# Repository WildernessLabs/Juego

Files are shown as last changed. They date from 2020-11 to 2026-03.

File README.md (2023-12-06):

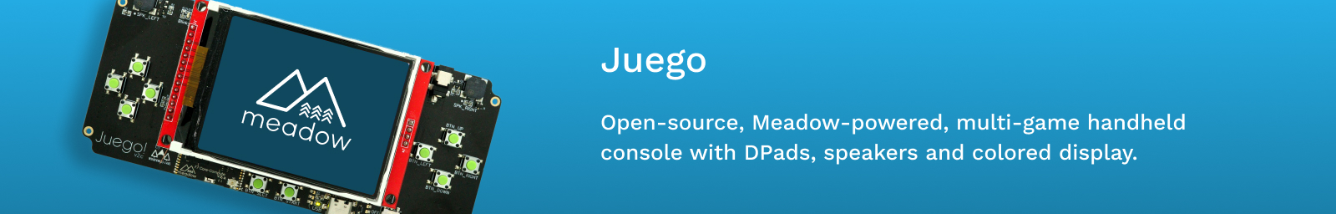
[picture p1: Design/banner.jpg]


# Juego

Open-source, Meadow-powered, multigame handheld console with DPads, speakers and a colored display.

#### Are you brand new to Meadow?

If you've never deployed a Meadow app before, you'll want to check out the [Getting Started Guide](https://developer.wildernesslabs.co/Meadow/Getting_Started/) which will get your development environment up and running and validate that you can build and deploy.

## Contents
* [Purchasing or Building](#purchasing-or-building)
* [Getting Started](#getting-started)
* [Hardware Specifications](#hardware-specifications)
* [Additional Samples](#additional-samples)
* [Juego Hack Kit Version](#juego-hack-kit-version)
* [Support](#support)

## Purchasing or Building

<table width="100%">
    <tr>
        <td>
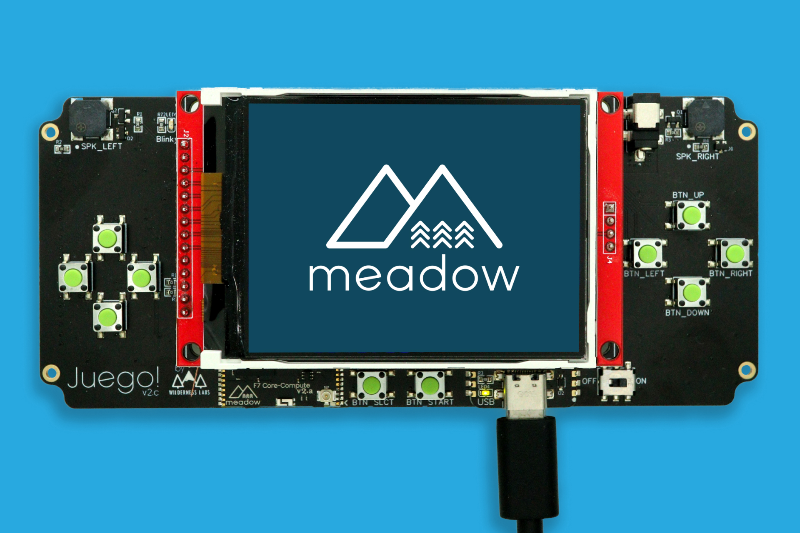
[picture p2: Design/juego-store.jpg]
            
        </td>
        <td>
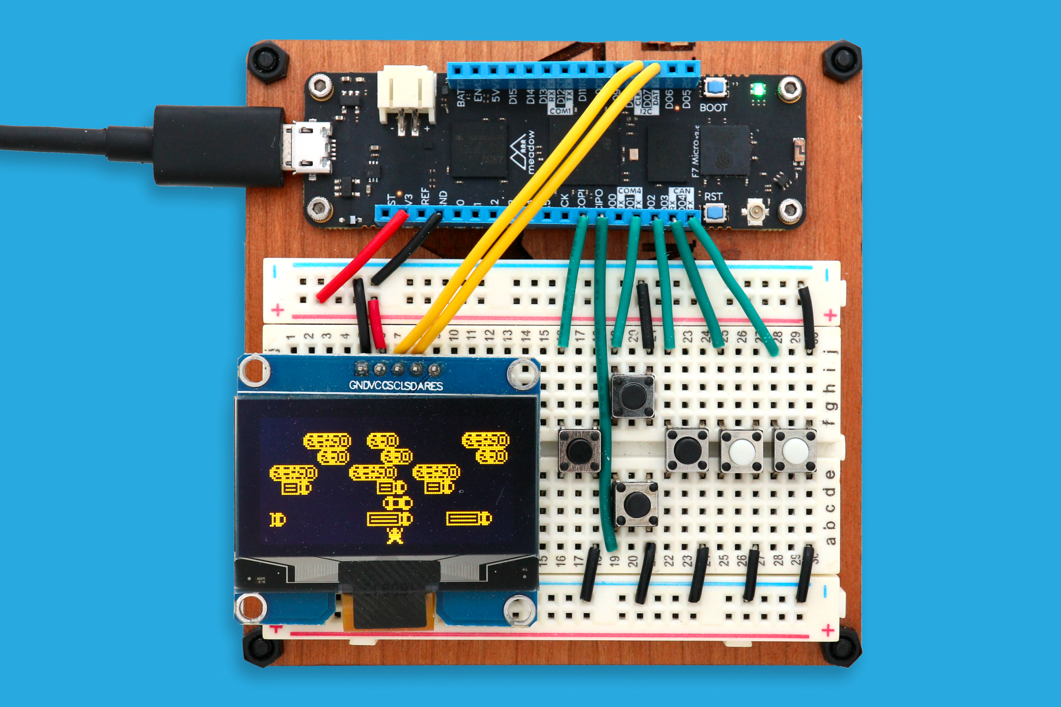
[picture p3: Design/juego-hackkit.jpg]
             
        </td>
    </tr>
    <tr>
        <td>
            You can get a Juego board from the <strong><a href="https://store.wildernesslabs.co/collections/frontpage/products/juego">Wilderness Labs store</a></strong>.
        </td>
        <td> 
            You can also build a simpler Juego using a monocolor display and push buttons.
        </td>
    </tr>
</table>

## Getting Started

### Playing Juego

Do you have a brand new Juego and you just wanna play some games? Check out the [Juego.Samples repo](https://github.com/WildernessLabs/Juego.Samples) with some games you can play out of the box:

Screenshot of the Juego.Samples repo readme showing several games that can be played. (https://github.com/WildernessLabs/Juego.Samples)

#### Are you brand new to Meadow?

If you've never deployed a Meadow app before, you'll want to check out the [Getting Started Guide](https://developer.wildernesslabs.co/Meadow/Getting_Started/) which will get your development environment up and running and validate that you can build and deploy.

### Using the Juego Hardware in your own App

To make using the hardware even simpler, we've created a [NuGet package](https://www.nuget.org/packages/Meadow.Juego) that instantiates and encapsulates the onboard hardware into a `Juego` class.

1. Add the ProjectLab Nuget package your project: 
    - `dotnet add package Meadow.Juego`, or
    - [Meadow.Juego Nuget Package](https://www.nuget.org/packages/Meadow.Juego)
    - [Explore in Fuget.org](https://www.fuget.org/packages/Meadow.Juego/0.1.0/lib/netstandard2.1/Juego.dll/Meadow.Devices/Juego)

2. Instantiate the Juego class:
```csharp
public class MeadowApp : App<F7CoreComputeV2>
{
    IJuegoHardware juego;

    public override Task Initialize()
    {
        juego = Juego.Create();
        ...
```

3. Access `Juego`'s onboard peripherals.

- To create a MicroGraphics object with Juego's Display:
```csharp
    ...
    if (juego.Display is { } display)
    {
        graphics = new MicroGraphics(display)
        {
            IgnoreOutOfBoundsPixels = true,
            CurrentFont = new Font12x16()
        };
        ....
    }
    ...
```

- To instantiate Juego's Select and Start buttons:
```csharp
    ...
    if (juego.SelectButton is { } selectButton)
    {
        selectButton.PressStarted += (s, e) => { ... };
        selectButton.PressEnded += (s, e) => { ... };
    }

    if (juego.StartButton is { } startButton)
    {
        startButton.PressStarted += (s, e) => { ... };
        startButton.PressEnded += (s, e) => { ... };
    }
    ...
```
- To use Juego's speakers:
```csharp
    ...
    for (int i = 0; i < 5; i++)
    {
        await juego.LeftSpeaker.PlayTone(
            new Frequency(440), TimeSpan.FromMilliseconds(500));
        await juego.RightSpeaker.PlayTone(
            new Frequency(540), TimeSpan.FromMilliseconds(500));
    }
    ...
```

## Hardware Specifications

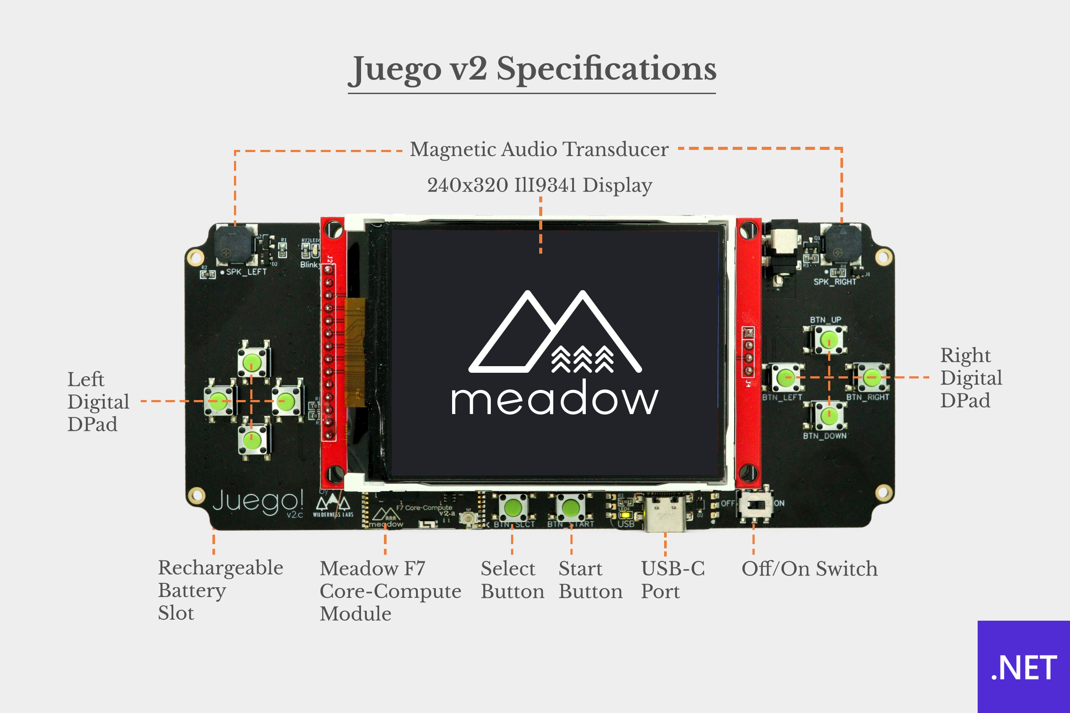
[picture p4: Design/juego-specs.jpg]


<table>
    <tr>
        <td><strong>ILI9341</strong> - 240x320 RGB LED display</td>
    </tr>
    <tr>
        <td><strong>Magnetic Audio Transducers</strong> - A pair of High quality piezo speakers</td>
    </tr>
    <tr>
        <td><strong>DPads</strong> - Directional Pads on either side of the display.</td>
    </tr>
    <tr>
        <td><strong>Select/Start Buttons</strong> - Classical Select and Start buttons</td>
    </tr>
    <tr>
        <td><strong>USB-C port</strong> - Port used to build/deploy apps to Juego</td>
    </tr>
    <tr>
        <td><strong>Rechargable Battery Slot</strong> - To play on the go</td>
    </tr>
    <tr>
        <td><strong>On/Off switch</strong> - Used to turn the Juego on and off</td>
    </tr>
</table>

You can find the schematics and other design files in the [Hardware folder](Source/Hardware).

## Additional Samples

1. **[Setup your Meadow Build Environment](http://developer.wildernesslabs.co/Meadow/Getting_Started/Deploying_Meadow/)** - If you haven't deployed a Meadow app before, you'll need to setup your IDE extension(s), deploy Meadow.OS, etc.
2. **[Run the Demo App](Source/Juego_Demo/)** - Deploy the Juego demonstration app to see the built in peripherals at work.
3. **[Check out the Juego.Samples repo](https://github.com/WildernessLabs/Juego.Samples)** - We recommend cloning the [Juego.Samples](https://github.com/WildernessLabs/Juego.Samples) repo. There you'll find a bunch of awesome samples that you can run right out-of-the box! 
<a href="https://github.com/WildernessLabs/Juego.Samples">
    juego, iot, project, samples
</a>

## Juego Hack Kit Version

This was an early hardware project to create a Meadow handheld multi-game project designed to work with 128x64 or 320x240 single color displays (SSD1306 or SSD1309)

Includes five games:

- FrogIt
- Pong
- Span4 (2-player match 4 game)
- Snake
- Tetraminos (inspired by Tetris)

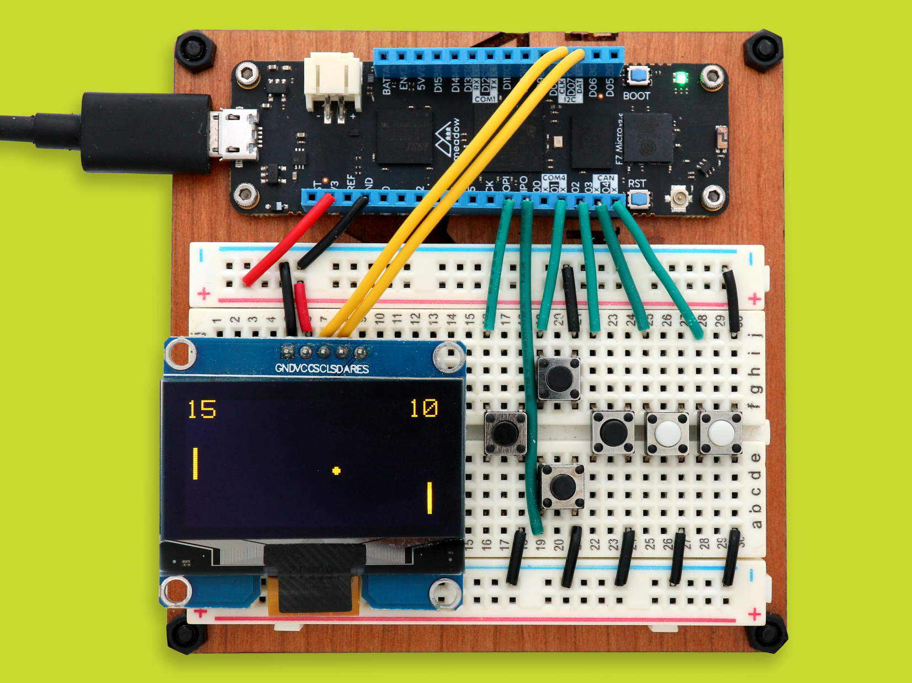
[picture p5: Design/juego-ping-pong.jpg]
"Image of Juego Meadow prototype hardware"


### Fritzing Diagrams of Juego using a Meadow Dev Kit

<table width="100%">
    <tr>
        <td>
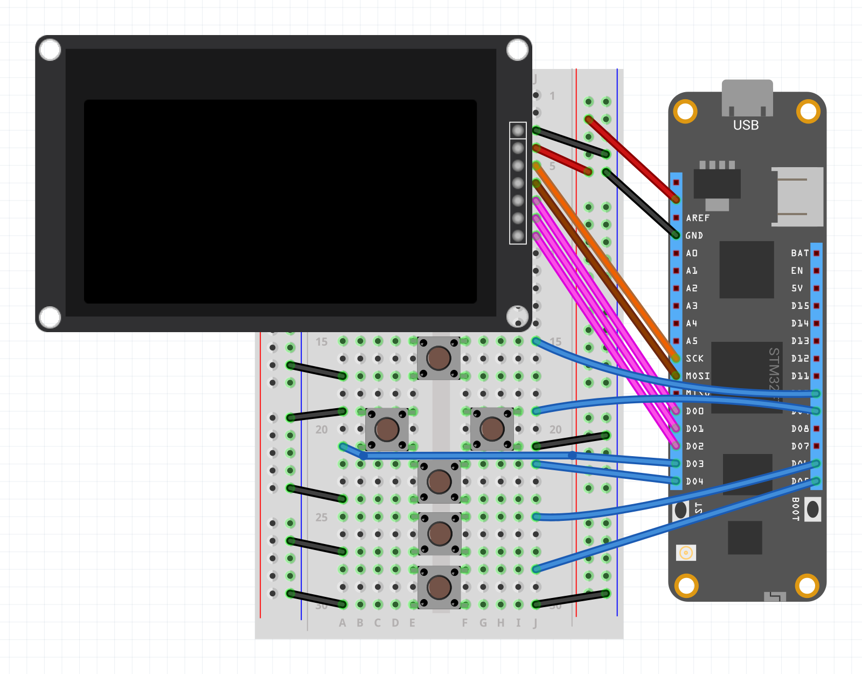
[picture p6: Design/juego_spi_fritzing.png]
            
        </td>
        <td>
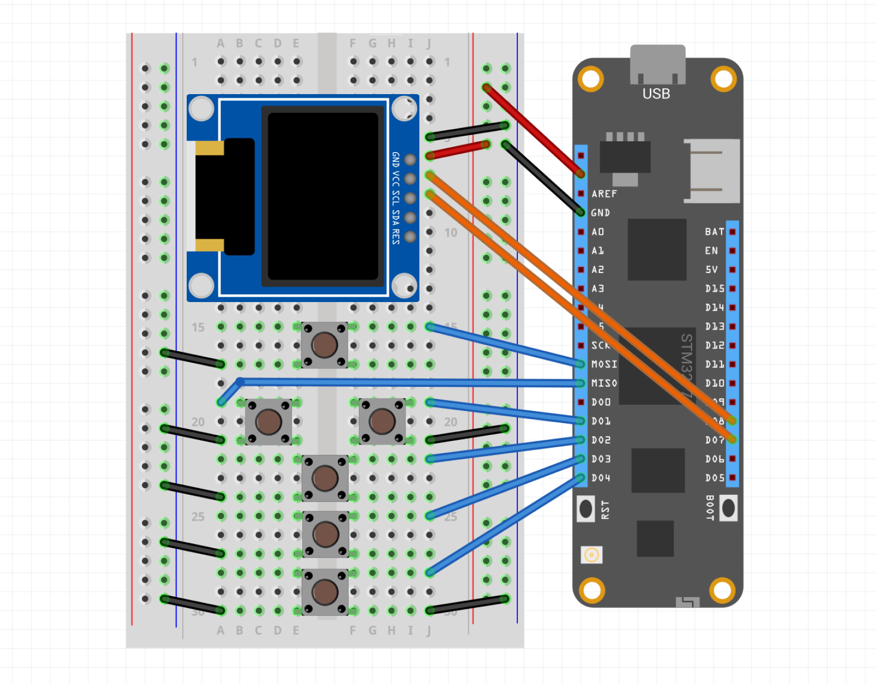
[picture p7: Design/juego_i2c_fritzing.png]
             
        </td>
    </tr>
    <tr>
        <td>
            Juego using a SSD1309 Display connected via SPI and Push Buttons.
        </td>
        <td> 
            Juego using a SSD1309 Display connected via I2C and Push Buttons.
        </td>
    </tr>
</table>

## Support

Having trouble building/running these projects? 
* File an [issue](https://github.com/WildernessLabs/Meadow.Desktop.Samples/issues) with a repro case to investigate, and/or
* Join our [public Slack](http://slackinvite.wildernesslabs.co/), where we have an awesome community helping, sharing and building amazing things using Meadow.

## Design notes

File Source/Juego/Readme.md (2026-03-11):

# Meadow.Juego

**Convenience library for the Meadow Juego handheld game console**

The **Juego** library is included in the **Meadow.Juego** nuget package and is designed for the [Wilderness Labs](www.wildernesslabs.co) Meadow .NET IoT platform.

Juego is an open-source, Meadow-powered, multigame handheld console with dual DPads, stereo speakers, and a color display.

For more information on developing for Meadow, visit [developer.wildernesslabs.co](http://developer.wildernesslabs.co/).

To view all Wilderness Labs open-source projects, including samples, visit [github.com/wildernesslabs](https://github.com/wildernesslabs/).

## Onboard Hardware

| Peripheral | Description |
|---|---|
| ILI9341 | 240x320 color TFT display |
| BMI270 | Inertial measurement unit / accelerometer |
| Left DPad | 4-way directional pad (left side) |
| Right DPad | 4-way directional pad (right side) |
| Select / Start | Classic game console buttons |
| Piezo speakers | Stereo left and right audio transducers |
| USB-C | Build and deploy port |
| Battery slot | Rechargeable battery for portable play |

## Installation

You can install the library from within Visual Studio using the NuGet Package Manager or from the command line using the .NET CLI:

`dotnet add package Meadow.Juego`

## Usage

```csharp
public class MeadowApp : App<F7CoreComputeV2>
{
    IJuegoHardware juego;

    public override Task Initialize()
    {
        juego = Juego.Create();

        if (juego.Display is { } display)
        {
            var graphics = new MicroGraphics(display)
            {
                IgnoreOutOfBoundsPixels = true,
                CurrentFont = new Font12x16()
            };
            graphics.DrawText(10, 10, "Hello, Juego!");
            graphics.Show();
        }

        if (juego.Left_UpButton is { } upButton)
        {
            upButton.PressStarted += (s, e) => Resolver.Log.Info("Up pressed");
        }

        if (juego.SelectButton is { } selectButton)
        {
            selectButton.PressStarted += (s, e) => Resolver.Log.Info("Select pressed");
        }

        if (juego.MotionSensor is { } imu)
        {
            imu.Updated += (s, e) =>
                Resolver.Log.Info($"X:{e.New.Acceleration3D?.X.Gravity:0.0}g");
        }

        return Task.CompletedTask;
    }

    public override async Task Run()
    {
        if (juego.MotionSensor is { } imu)
            imu.StartUpdating(TimeSpan.FromMilliseconds(250));

        if (juego.LeftSpeaker != null)
            await juego.LeftSpeaker.PlayTone(new Frequency(440), TimeSpan.FromMilliseconds(500));

        if (juego.RightSpeaker != null)
            await juego.RightSpeaker.PlayTone(new Frequency(540), TimeSpan.FromMilliseconds(500));

        await Task.Delay(Timeout.Infinite);
    }
}
```

## How to Contribute

- **Found a bug?** [Report an issue](https://github.com/WildernessLabs/Meadow_Issues/issues)
- Have a **feature idea or driver request?** [Open a new feature request](https://github.com/WildernessLabs/Meadow_Issues/issues)
- Want to **contribute code?** Fork the [Juego](https://github.com/WildernessLabs/Juego) repository and submit a pull request against the `develop` branch

## Need Help?

If you have questions or need assistance, please join the Wilderness Labs [community on Slack](http://slackinvite.wildernesslabs.co/).

## About Meadow

Meadow is a complete, IoT platform with defense-grade security that runs full .NET applications on embeddable microcontrollers and Linux single-board computers including Raspberry Pi and NVIDIA Jetson.

### Build

Use the full .NET platform and tooling such as Visual Studio and plug-and-play hardware drivers to painlessly build IoT solutions.

### Connect

Utilize native support for WiFi, Ethernet, and Cellular connectivity to send sensor data to the Cloud and remotely control your peripherals.

### Deploy

Instantly deploy and manage your fleet in the cloud for OtA, health-monitoring, logs, command + control, and enterprise backend integrations.

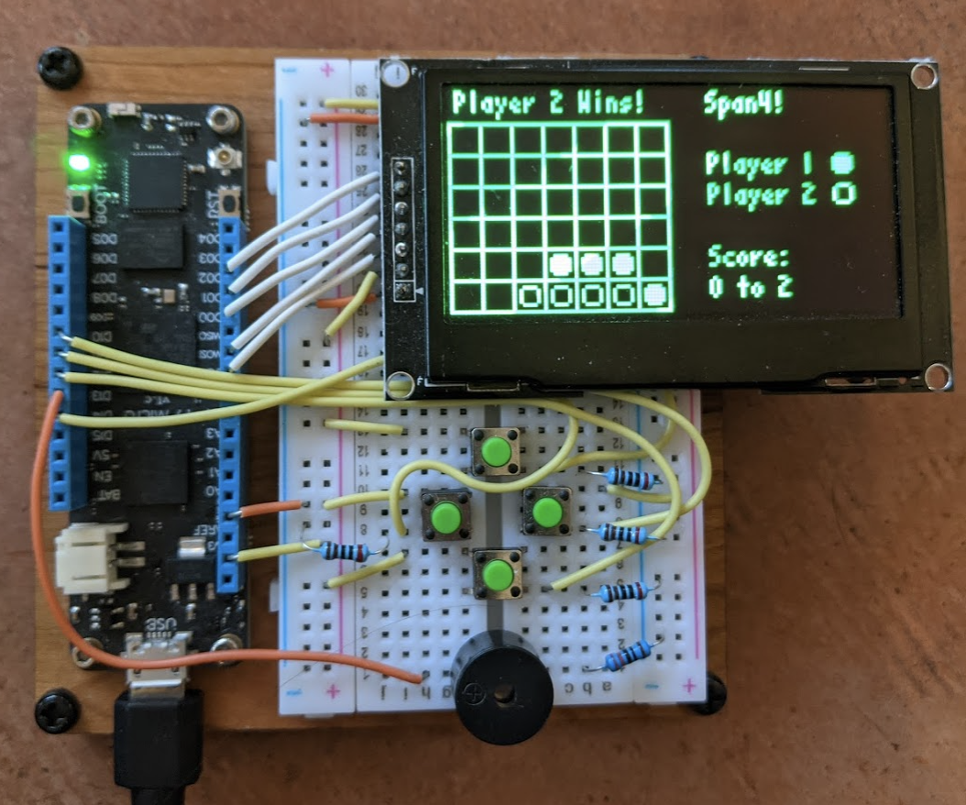
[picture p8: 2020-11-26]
Design/juego.png

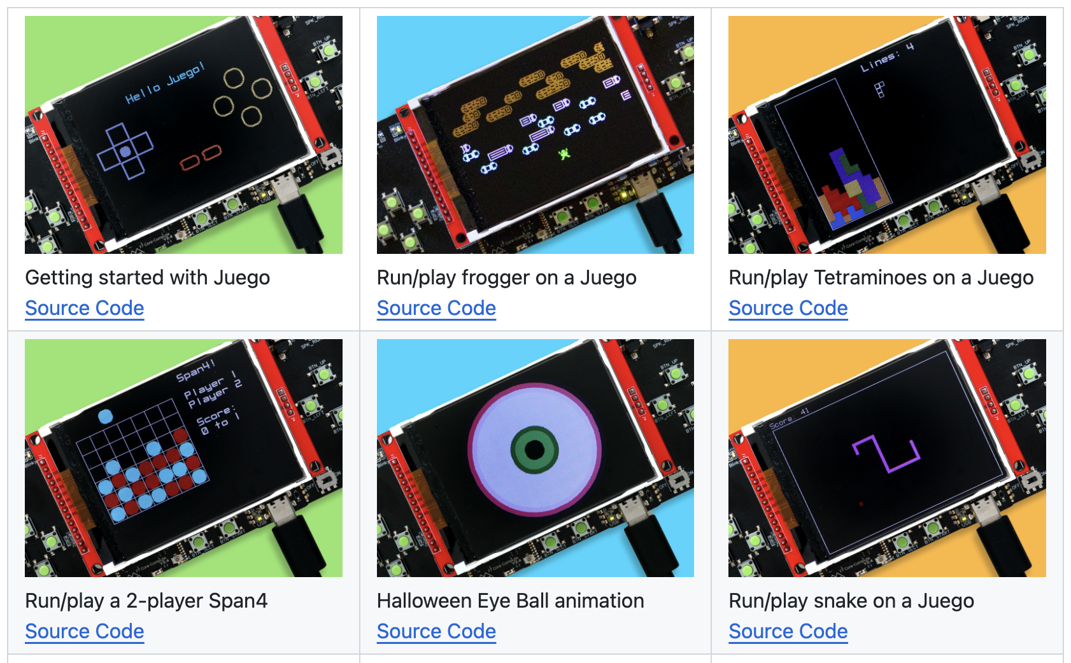
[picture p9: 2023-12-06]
Juego.Samples_Screenshot.png

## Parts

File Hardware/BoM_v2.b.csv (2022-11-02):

ID | Name | Designator | Footprint | Quantity | Manufacturer Part | Manufacturer | Supplier | Supplier Part | Price
1 | Up | BTN_DOWN,BTN_LEFT,BTN_RIGHT,BTN_SLCT,BTN_START,BTN_UP,DPAD_DOWN,DPAD_LEFT,DPAD_RIGHT,DPAD_UP | TACTILE_SWITCH_TALL | 10
2 | BAS70KFILM | D1,D2 | SOT323 | 2 | BAS70KFILM | ST Microelectronics
3 | PJ-030CH-SMT-TR | J1 | CUI_PJ-030CH-SMT-TR | 1
4 | EAST1608GA0 | LED5 | LED0603-RD | 1 | EAST1608GA0 | Everlight
5 | FDV305N | Q1,Q2 | SOT-23_L2.9-W1.3-P0.95-LS2.4-BR | 2 | FDV305N | Fairchild |  | C65189 | 0.044
6 | 10kΩ | R1,R3 | R0603 | 2 | RC0603FR-0710KL | Yageo
7 | 20Ω | R2,R4 | R0603 | 2 | RC0603FR-0720RL | Yageo
8 | 4.7k | R5,R6 | R0603 | 2 | RC0603FR-074K7L | Yageo
9 | 2k | R72 | R0603 | 1 | RC0603FR-072KL | Yageo
10 | 452403012014 | S1 | 452403012014 | 1
11 | CMT-7525-80-SMT | SPK_LEFT,SPK_RIGHT | CMT-7525S | 2 | CMT-7525-80-SMT | CUI Devices
12 | Meadow Core-Compute USB-C, Power, Boot, and Reset Addon Module | U1 | MEADOW CORE-COMPUTE USB-C, POWER, BOOT, RESET ADDON MODULE | 1 |  | Wilderness Labs
13 | 1043P | U3 | BAT-TH_KEYSTONE-1043P | 1 | 1043P | Keystone | Digi-Key
14 | JOYSTICK-PSP1000 | U4 | JOYSTICK-PSP1000 | 1
15 | Meadow Core-Compute Addon Module - Solar Battery Power | U6 | MEADOW CORE-COMPUTE SOLAR & BATTERY POWER ADDON MODULE | 1 |  | Wilderness Labs
16 | Meadow F7v2 Core-Compute Module - Logical | U7 | MEADOW_F7V2_CORE_COMPUTE | 1 |  | Wilderness Labs
17 | ILI9341 LCD TFT 3.2 | U8 | ILI9341 TFT LCD 3.2" | 1
18 | MCP23008T-E/SS | U9,U11,U12 | SSOP-20_L7.2-W5.3-P0.65-LS7.8-TL | 3 | MCP23008T-E/SS | Microchip Tech | LCSC | C629435 | 2.039

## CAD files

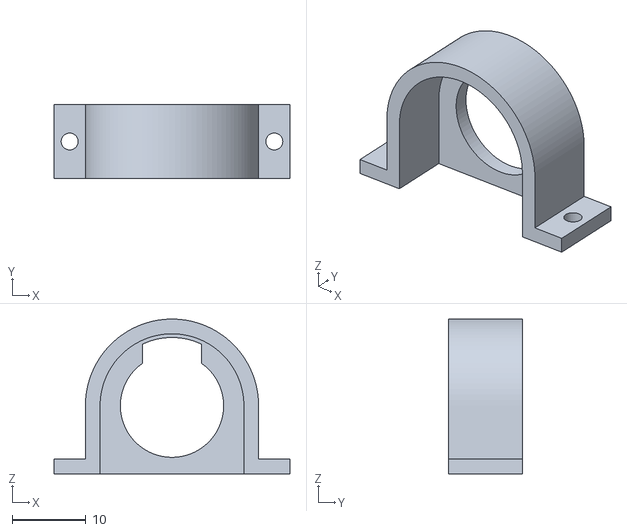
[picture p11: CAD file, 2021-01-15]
Industrial_Design/Battery_Mount_Open_End.stl
32.0 x 10.0 x 21.0

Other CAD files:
Industrial_Design/2200mAh Battery Holder.f3z

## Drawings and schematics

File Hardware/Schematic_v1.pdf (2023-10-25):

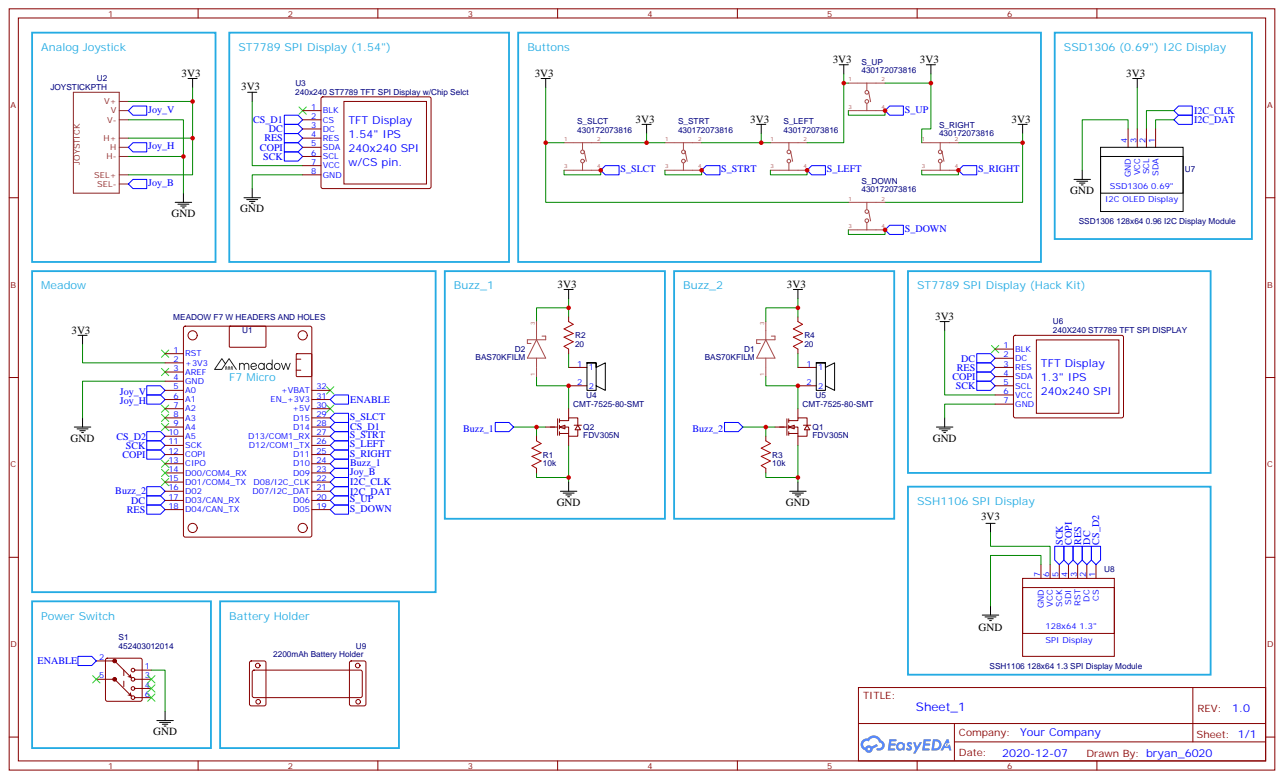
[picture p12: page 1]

ST7789 SPI Display (Hack Kit)

MEADOW F7 W HEADERS AND HOLES

SSH1106 SPI Display
SPI Display SCK COPI RES DC

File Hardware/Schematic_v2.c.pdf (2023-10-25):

# Buttons Power Switch

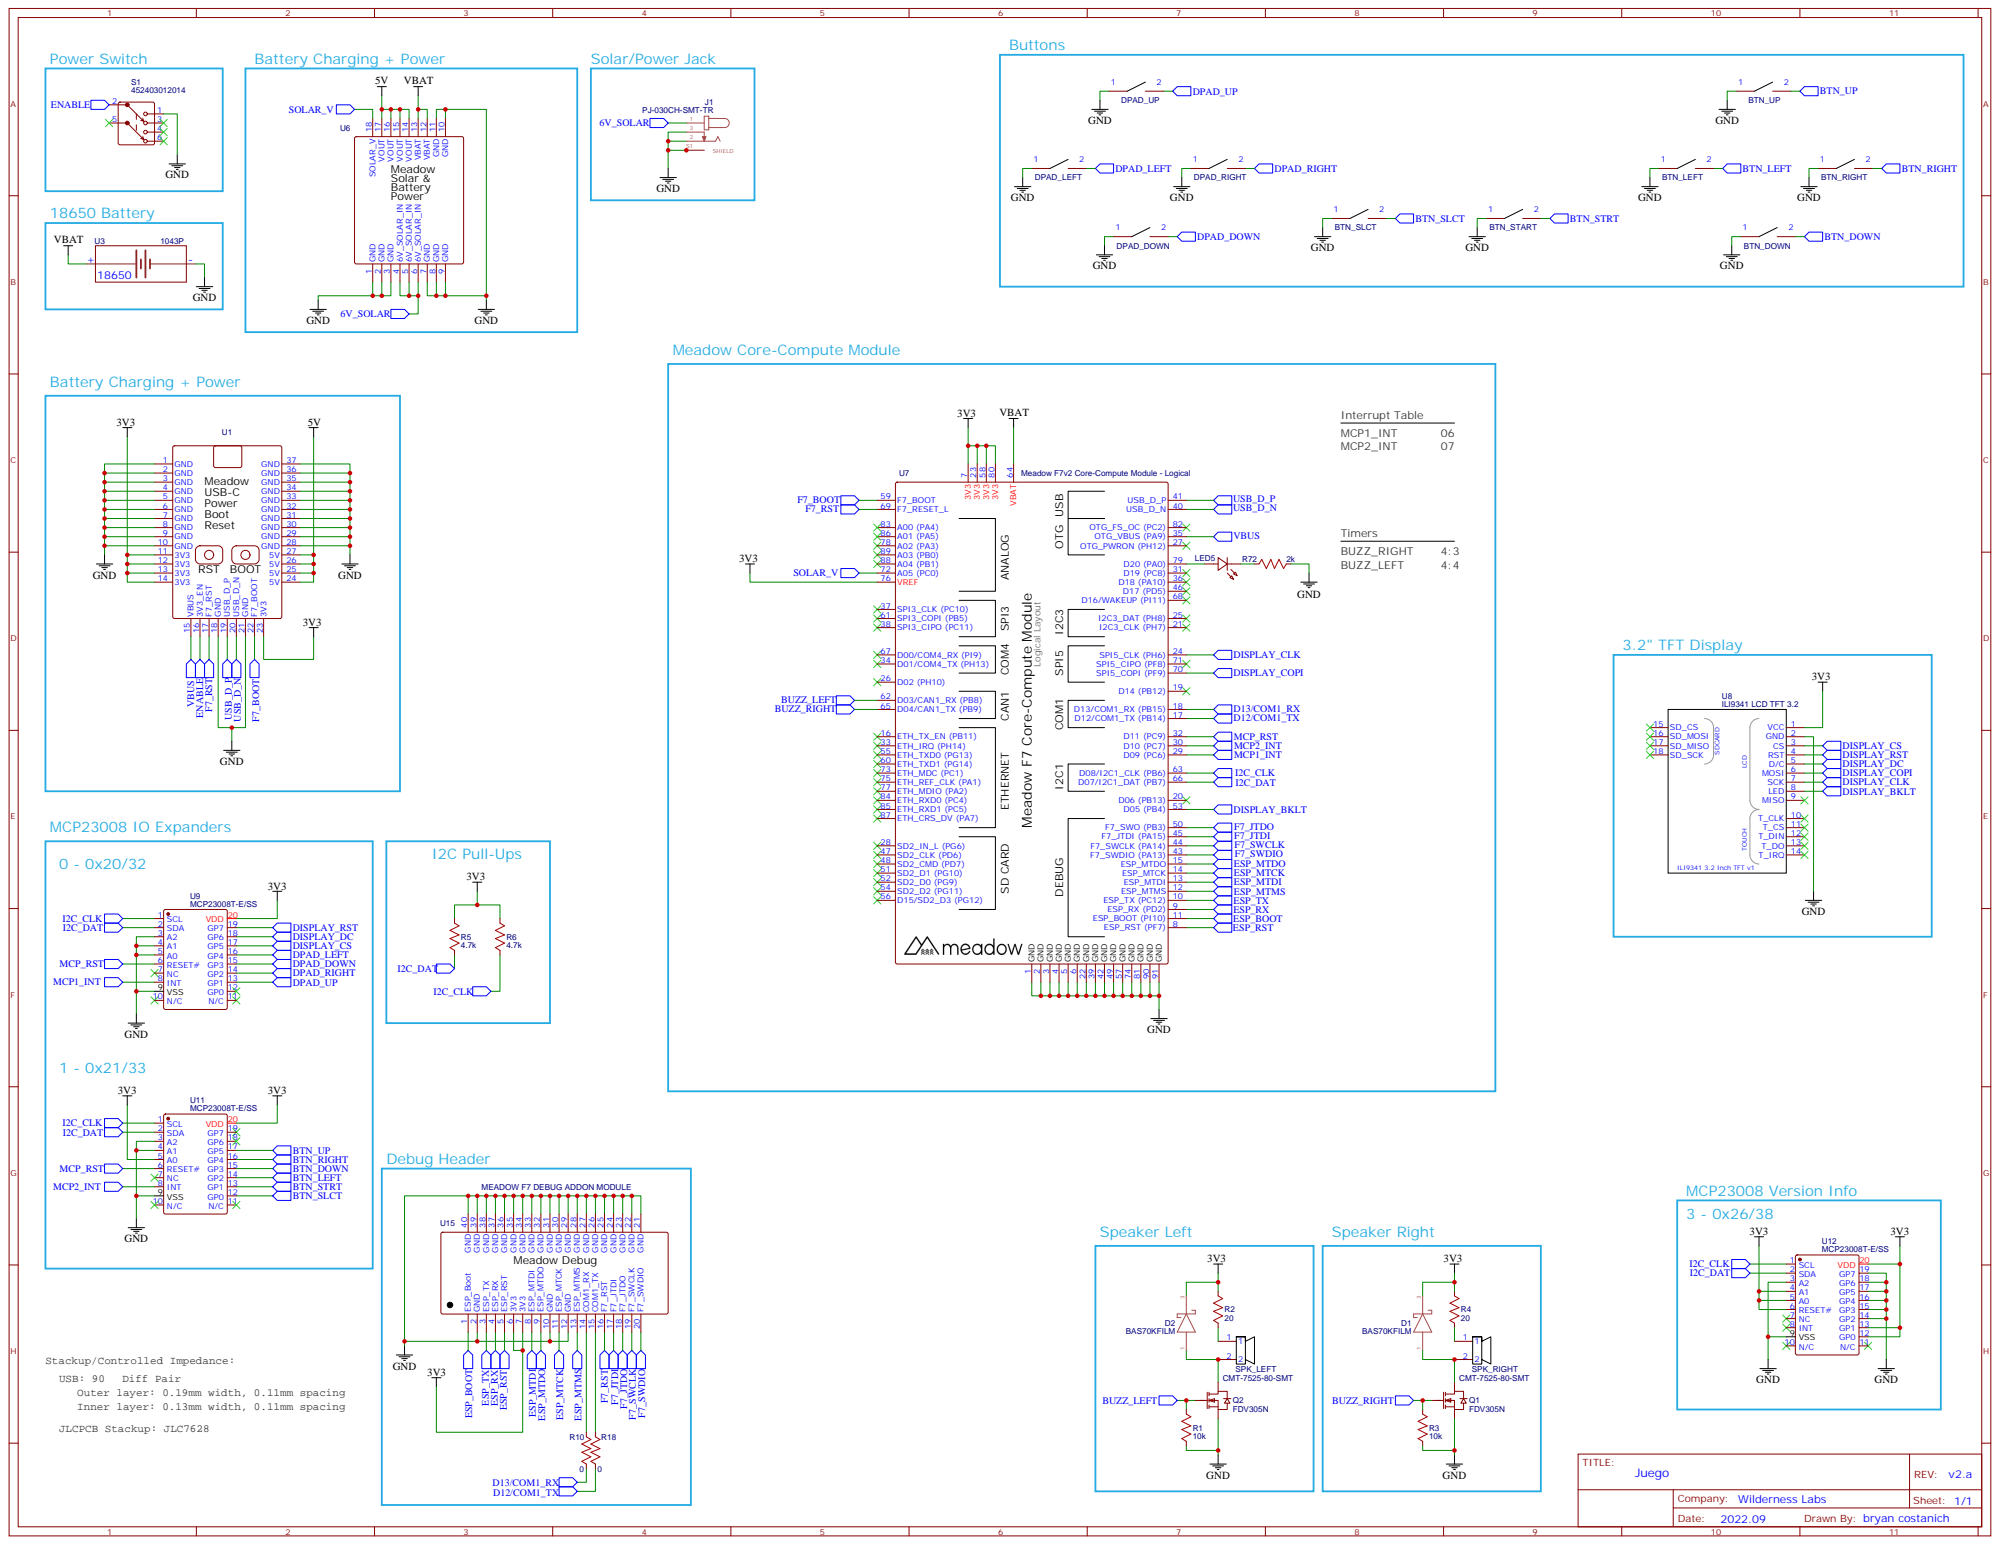
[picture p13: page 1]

9 GND 10 GND 11 VBAT 12 VBAT 13 VOUT 14 VOUT 15 VOUT 16 VOUT 17 SOLAR_V 18

Meadow Core-Compute Module

5V 24 5V 25 5V 26 5V 27 GND 28 GND 29 GND 30 GND 31 GND 32 GND 33 GND 34 GND 35 GND 36 GND 37

MEADOW F7 DEBUG ADDON MODULE

F7_SWDIO 20 GND 21 GND 22 GND 23 GND 24 GND 25 GND 26 GND 27 GND 28 GND 29 GND 30 GND 31 GND 32 GND 33 GND 34 GND 35 GND 36 GND 37 GND 38 GND 39 GND 40

Stackup/Controlled Impedance:
Outer layer: 0.19mm width, 0.11mm spacing
Inner layer: 0.13mm width, 0.11mm spacing
JLCPCB Stackup: JLC7628

Drawn By: bryan costanich

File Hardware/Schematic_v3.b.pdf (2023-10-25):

# Buttons Power Switch

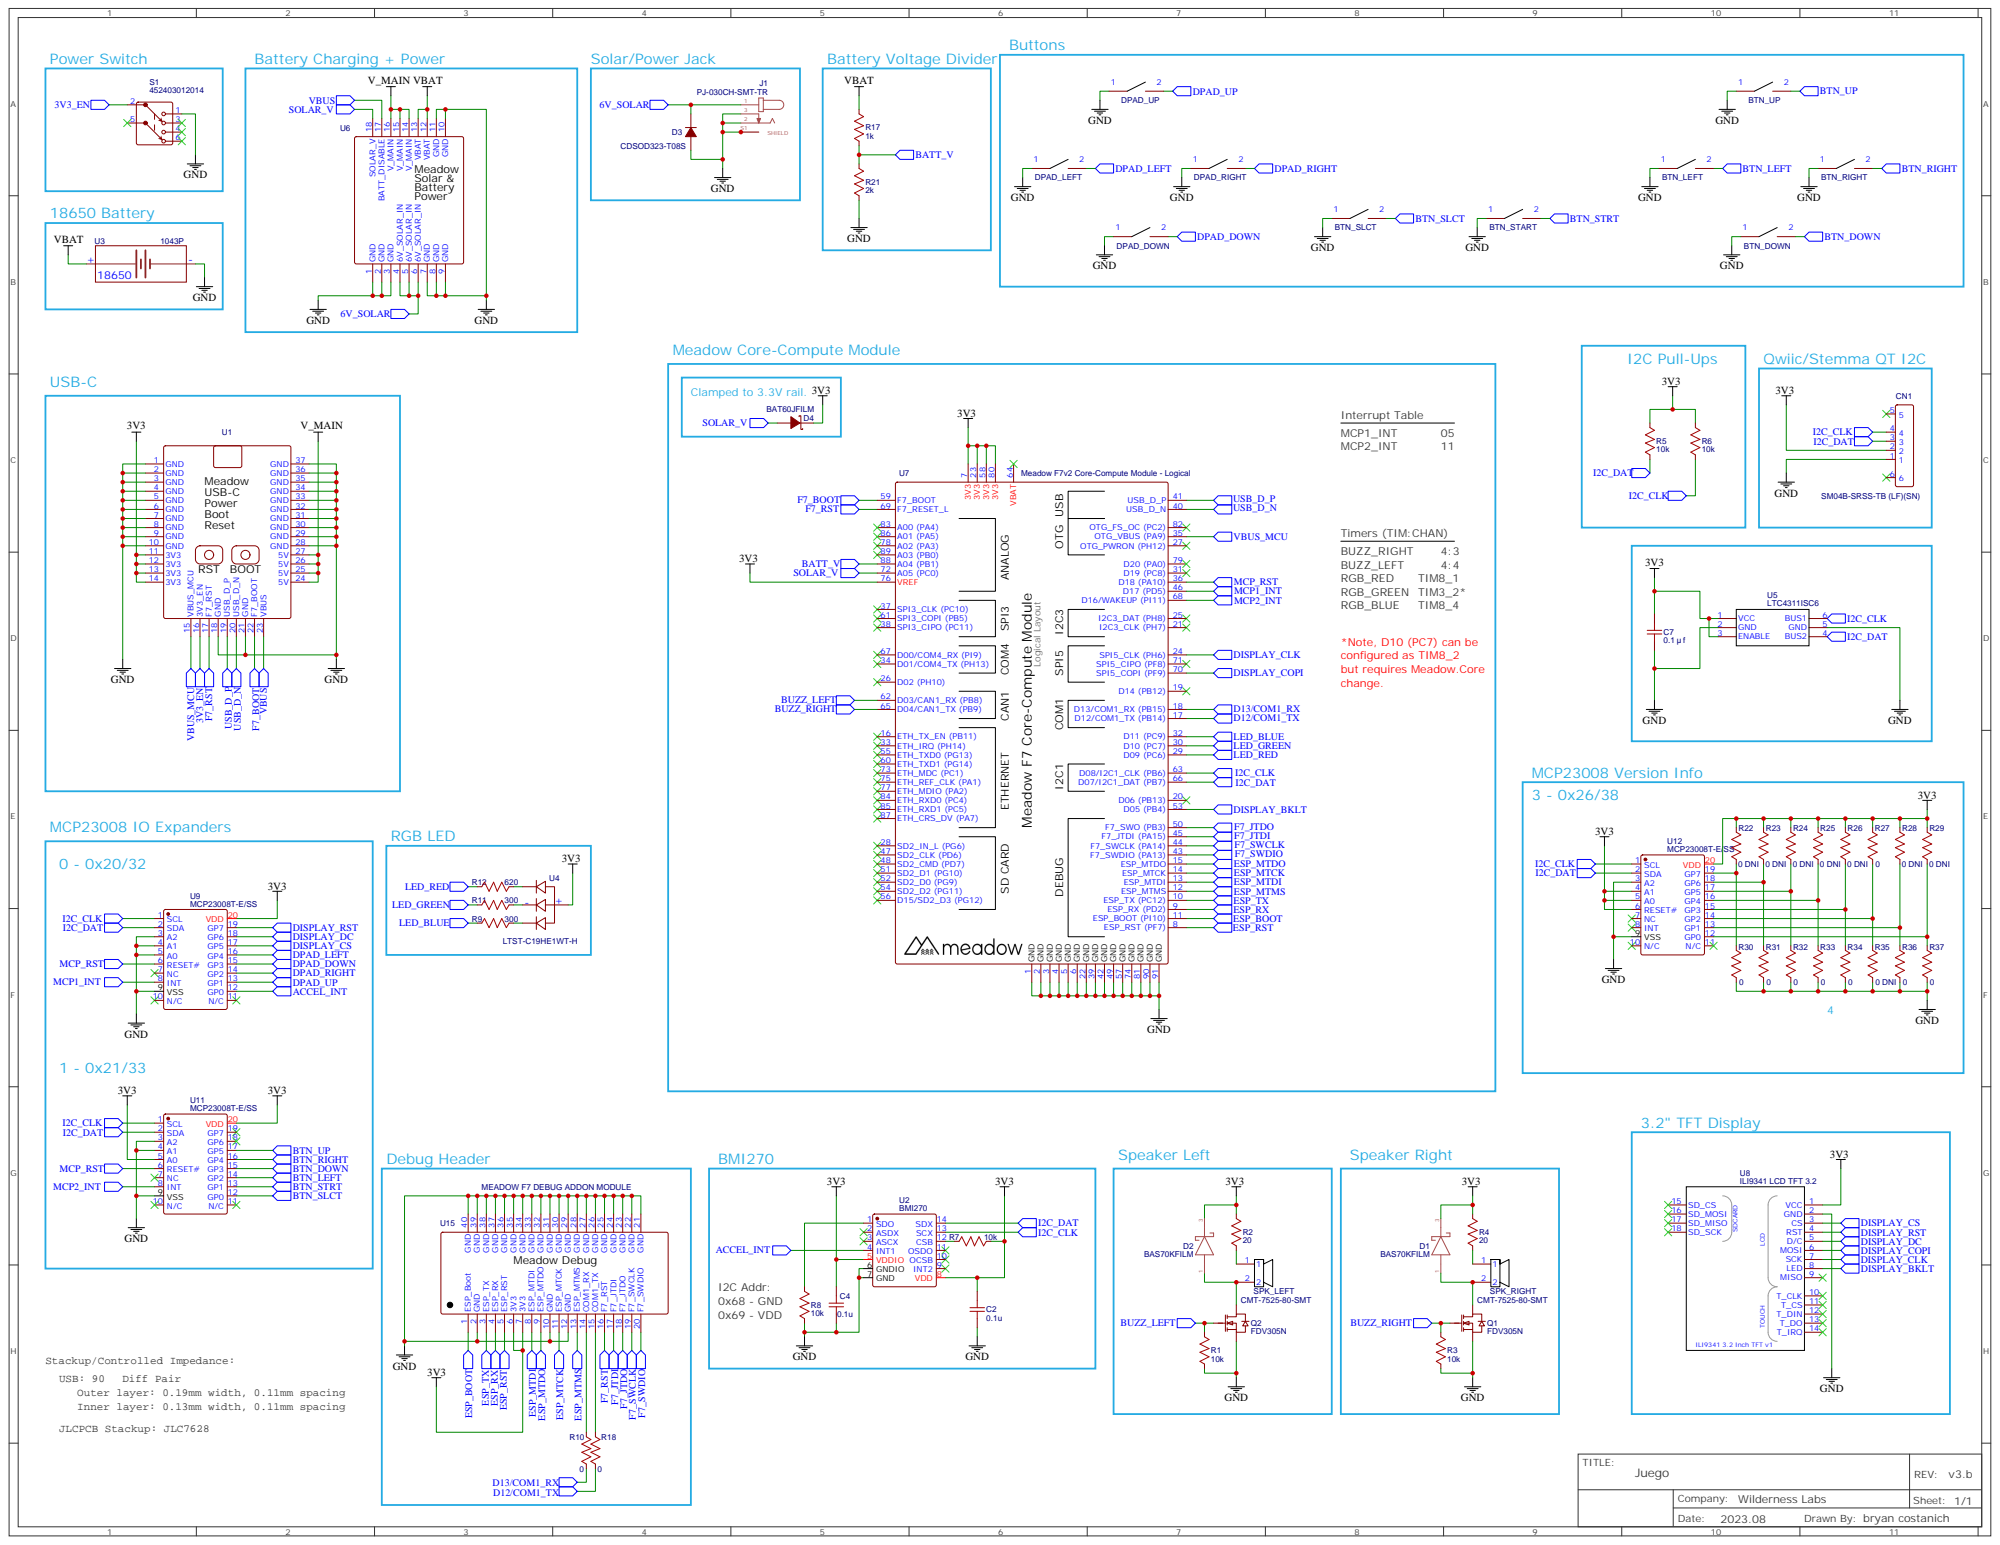
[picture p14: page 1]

9 GND 10 GND 11 VBAT 12 VBAT 13 V_MAIN 14 V_MAIN 15 V_MAIN 16 BATT_DISABLE 17 SOLAR_V 18

Meadow Core-Compute Module

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

SM04B-SRSS-TB (LF)(SN)

*Note, D10 (PC7) can be
configured as TIM8_2
but requires Meadow.Core
change.

MEADOW F7 DEBUG ADDON MODULE

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

Drawn By: bryan costanich

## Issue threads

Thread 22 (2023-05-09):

Hardware request: add accelerometer & vibration motor

adrianstevens, 2023-05-09:
I think this was Bryan's idea originally, if it doesn't impact the cost too heavily, it would be fun to add an accelerometer.

And if we got really fancy we could also add a vibration motor.

I also think we talked about adding a qwiic connector.

adrianstevens, 2024-02-07:
Accelerometer and qwiic connector added

Leaving issue open to track vibration motor request

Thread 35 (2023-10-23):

Juego PCB request: 5v and MISO support

KallDrexx, 2023-10-23:
Today my Microgpu adapter boards successfully slot into the Juego in the same pins that the LCD currently slots into.  However, the Juego's PCB has two minor issues that limits its potential.

The first is that the MISO pin to the LCD pins isn't connected.  While most of the GPU operations are fire and forget, having the ability to read data back from the GPU is useful (for example, the GPU telling the meadow its resolution).

Likewise, at some point I intend to build a proper circuit board with the esp32-s3 embedded in it.  While the esp32-s3 should be able to be powered by the 3.3v rails, I need a 5v power source still for the display.  If the Juego has a 5v pin, then I would be able to power the GPU and display all from the Juego, without an extra usb cable.

bryancostanich, 2023-10-23:
oooh, that would be cool. drop in GPU/display board.

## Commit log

2020-11-26 Switched menu definition to hard coded instead of json - much faster
2021-01-15 Added Battery Mount
    [2200mAh Battery Holder.f3z, Battery_Mount_Open_End.stl]
2021-01-30 added buttons that don't seem to work.
2021-02-15 Add hardware config for prototype build
2021-02-19 Interval timer working
2022-11-02 Added hardware source
    [BOM_v1.a.csv]
2022-11-02 Updated v2.b hardware design files.
    [BOM_v1.a.csv, BoM_v2.b.csv]
2022-11-07 Add display and button validation to demo app
2022-12-21 Switch from Console.WL to Resolver.Log.*
2023-03-25 Bump display SPI speed to 48000
2023-03-25 Fix button mapping for v2c
2023-03-26 Create Juego nuget, folder restructure, v1 hardware class, cleanup
    [2200mAh Battery Holder.f3z, Battery_Mount_Open_End.stl, BoM_v2.b.csv]
2023-04-25 Set SPI bus on display + denugetize
2023-04-28 Set blinky forward voltage to green
2023-05-06 Bump I2C bus speed
2023-05-31 refactor required by interrupt port
2023-10-07 Add Display Connector
2023-12-06 added screenshot of juego samples
2024-02-09 Set SPI bus speed to 24mhz + minor cleanup
2024-02-11 Update namespace to Meadow.Devices and use file scoped namespaces
2026-02-24 Move the SPI initialized log outside of the try/catch
